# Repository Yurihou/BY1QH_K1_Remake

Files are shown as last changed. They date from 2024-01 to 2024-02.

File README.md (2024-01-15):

# BY1QH_K1_Remake
CQ DE BH9DWE! Elecraft is a famous amateur radio manufacturer but its rather expensive to afford. These days I tried to read and understood the original equipment Elecraft K1's principle and managed to modify it. So I push the PCB files to my GitHub and share it to all HAMs.

Firstly I read the manual and understood the schematic diagram of K1, found some components, such as JFET J309, is not available in online shopping network. So I modified the design a little bit. Then I bought and soldered the components of receiver of K1 on the board. After a series of debugging, I managed to make the circuit receiving CW signals on amateur bands. The testing video refers to https://www.bilibili.com/video/BV1d5411i7so
68414c2a40aba171e41130ed85432a5

The receiver is succeed in receiving but there is still some problems such as amplifier noise, RF filter attenuation and frequency drift, so I tried to draw the circuit into PCB. If the PCB version works well, I will continue adding functions and modifying design to improve its performance, such as adding frequency display, PLL, multi-band filter and band controller, transmitter, SSB module, antenna tuneing unit and so on.

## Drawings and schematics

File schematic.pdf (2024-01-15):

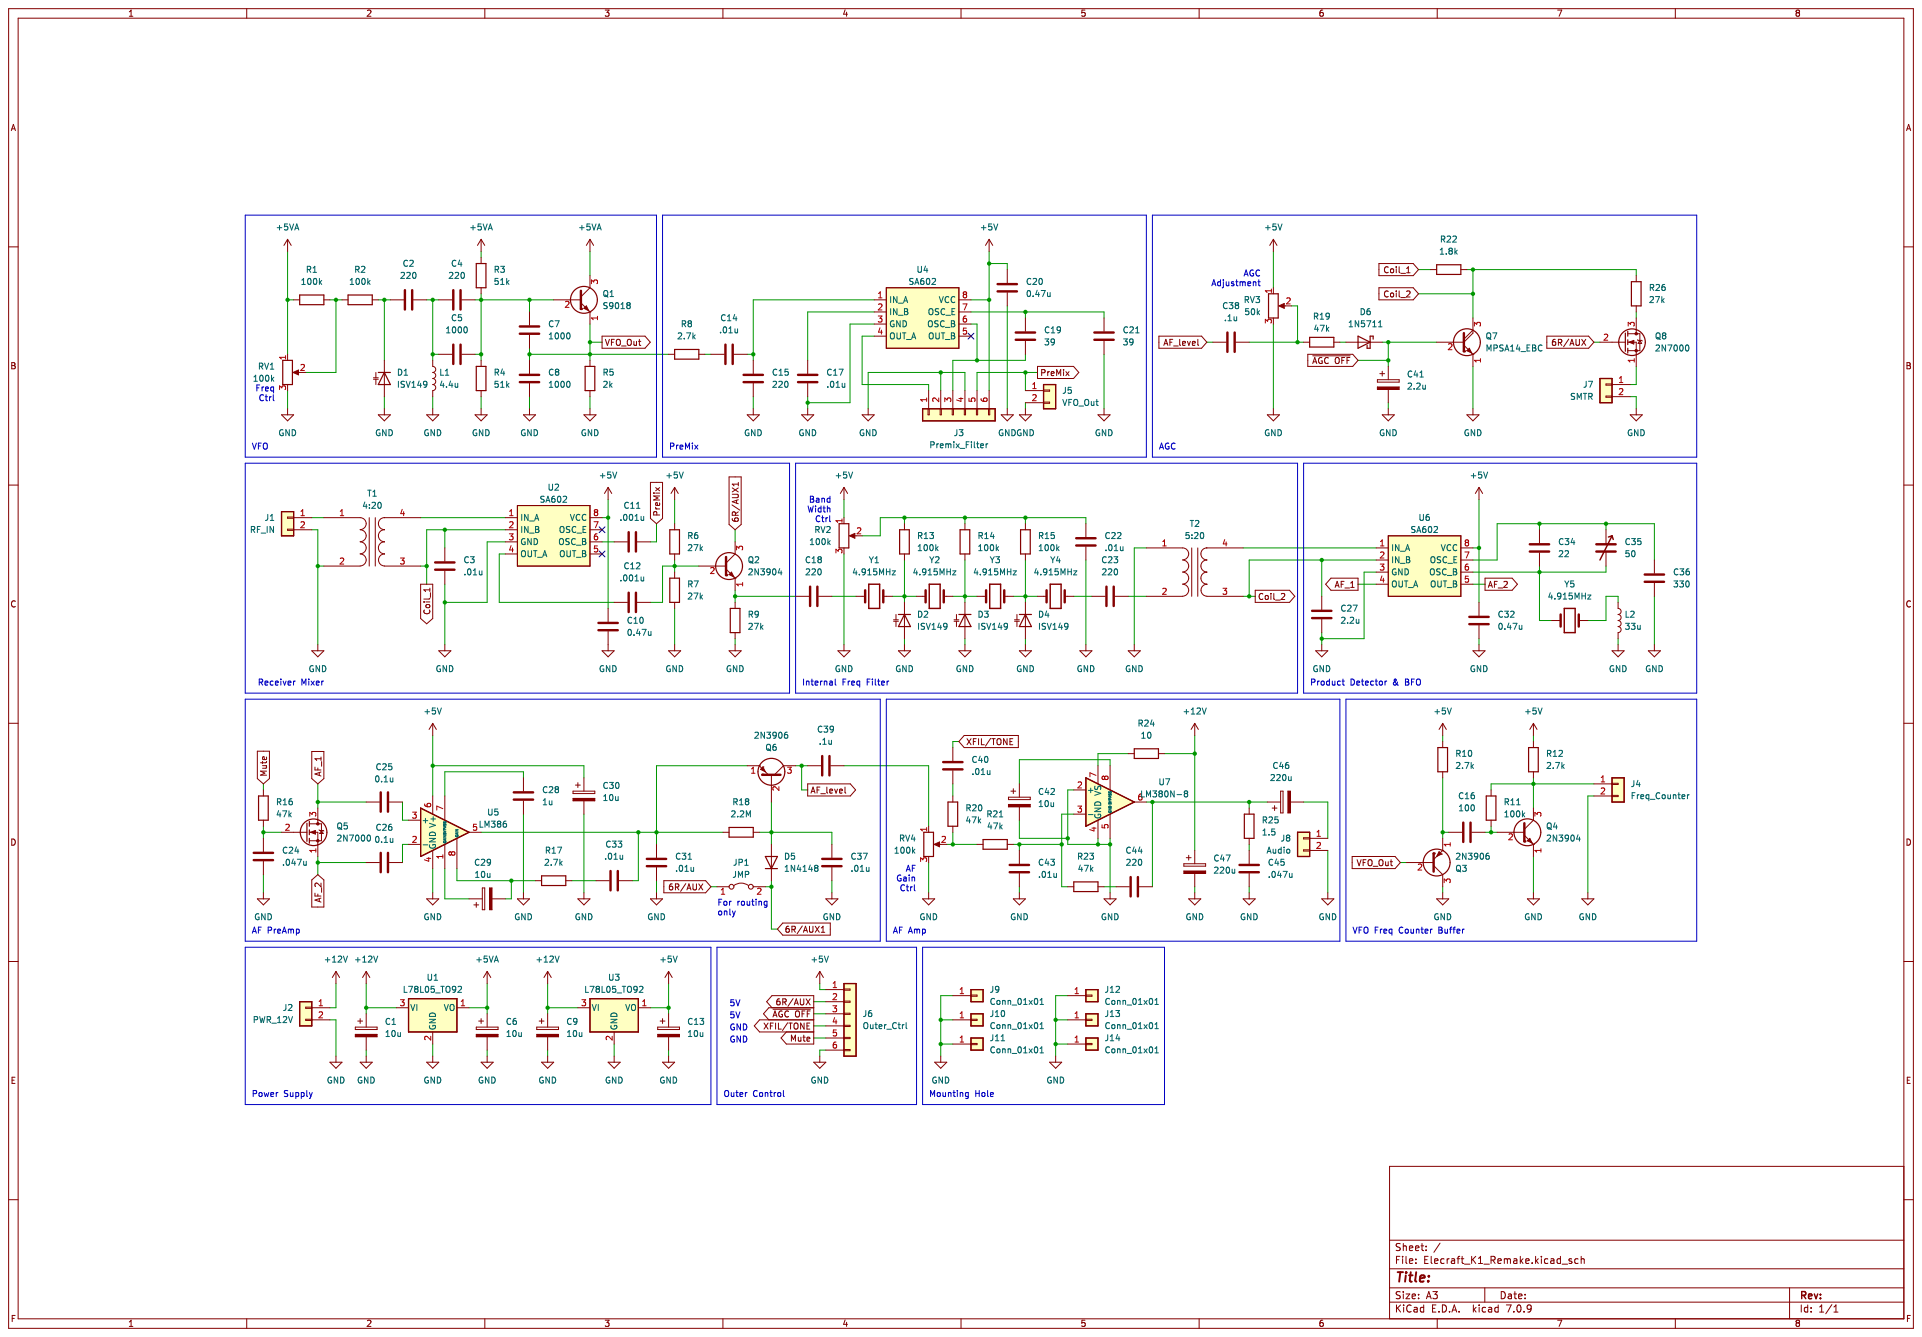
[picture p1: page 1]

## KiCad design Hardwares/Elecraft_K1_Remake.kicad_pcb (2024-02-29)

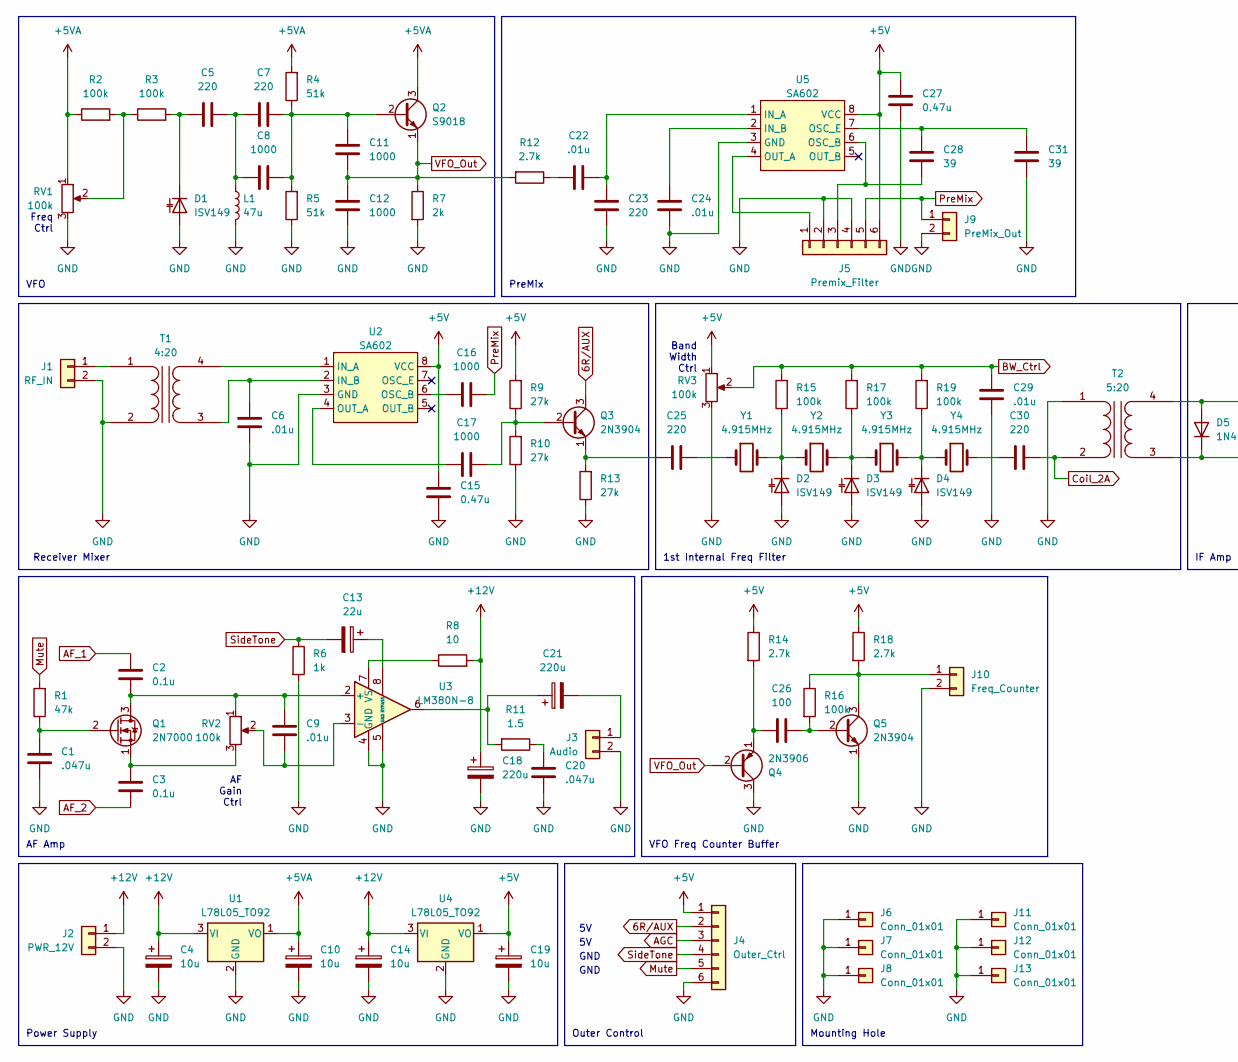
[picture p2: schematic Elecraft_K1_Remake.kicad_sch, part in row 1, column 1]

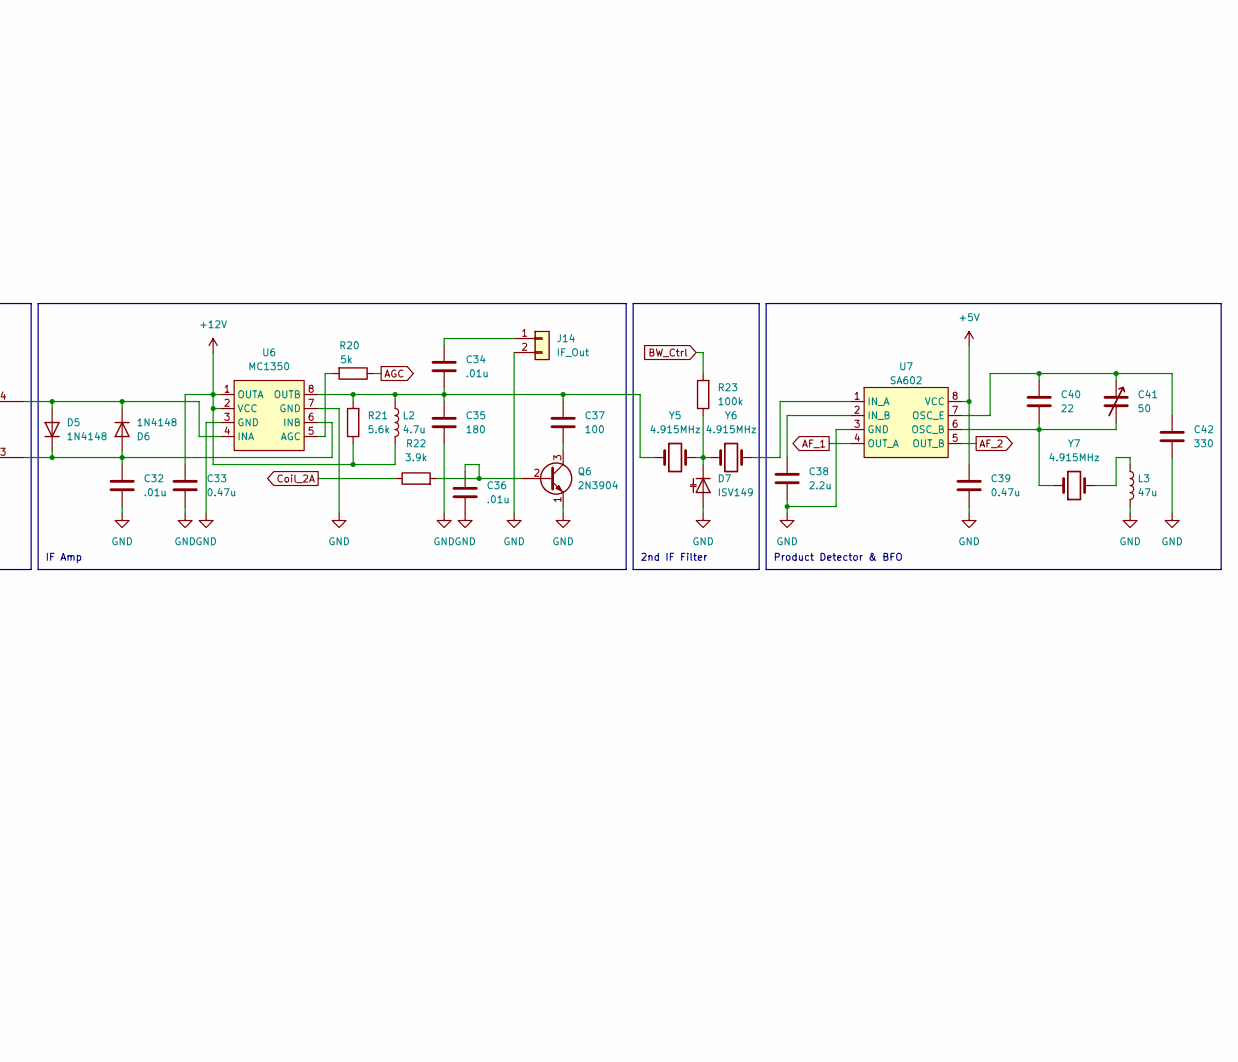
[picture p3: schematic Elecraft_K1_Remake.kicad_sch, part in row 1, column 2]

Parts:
C1, C20: .047u; C_Disc_D5.1mm_W3.2mm_P5.00mm
C2, C3: 0.1u; C_Disc_D5.1mm_W3.2mm_P5.00mm
C4, C10, C14, C19: 10u; CP_Radial_D5.0mm_P2.50mm
C5, C7, C23, C25, C30: 220; C_Disc_D5.1mm_W3.2mm_P5.00mm
C6, C9, C22, C24, C29, C32, C34, C36: .01u; C_Disc_D5.1mm_W3.2mm_P5.00mm
C8, C11, C12, C16, C17: 1000; C_Disc_D5.1mm_W3.2mm_P5.00mm
C13: 22u; CP_Radial_D8.0mm_P2.50mm
C15, C27, C33, C39: 0.47u; C_Disc_D5.1mm_W3.2mm_P5.00mm
C18, C21: 220u; CP_Radial_D8.0mm_P2.50mm
C26, C37: 100; C_Disc_D5.1mm_W3.2mm_P5.00mm
C28, C31: 39; C_Disc_D5.1mm_W3.2mm_P5.00mm
C35: 180; C_Disc_D5.1mm_W3.2mm_P5.00mm
C38: 2.2u; CP_Radial_D5.0mm_P2.50mm
C40: 22; C_Disc_D5.1mm_W3.2mm_P5.00mm
C41: 50; CP_Radial_Tantal_D6.0mm_P5.00mm
C42: 330; C_Disc_D5.1mm_W3.2mm_P5.00mm
D1, D2, D3, D4, D7: ISV149; TO-92-2
D5, D6: 1N4148; D_DO-35_SOD27_P7.62mm_Horizontal
J1: RF_IN; JST_XH_S2B-XH-A_1x02_P2.50mm_Horizontal
J2: PWR_12V; JST_XH_S2B-XH-A_1x02_P2.50mm_Horizontal
J3: Audio; JST_XH_S2B-XH-A_1x02_P2.50mm_Horizontal
J4: Outer_Ctrl; PinSocket_1x06_P2.54mm_Vertical
J5: Premix_Filter; PinSocket_1x06_P2.54mm_Vertical
J6, J7, J8, J11, J12, J13: Conn_01x01; MountingHole_3.2mm_M3_ISO14580_Pad
J9: PreMix_Out; JST_XH_S2B-XH-A_1x02_P2.50mm_Horizontal
J10: Freq_Counter; JST_XH_S2B-XH-A_1x02_P2.50mm_Horizontal
J14: IF_Out; JST_XH_S2B-XH-A_1x02_P2.50mm_Horizontal
L1, L3: 47u; L_Axial_L7.0mm_D3.3mm_P12.70mm_Horizontal_Fastron_MICC
L2: 4.7u; L_Axial_L7.0mm_D3.3mm_P12.70mm_Horizontal_Fastron_MICC
Q1: 2N7000; TO-92_Inline
Q2: S9018; TO-92_Inline
Q3, Q5, Q6: 2N3904; TO-92_Inline
Q4: 2N3906; TO-92_Inline
R1: 47k; R_Axial_DIN0207_L6.3mm_D2.5mm_P7.62mm_Horizontal
R2, R3, R15, R16, R17, R19, R23: 100k; R_Axial_DIN0207_L6.3mm_D2.5mm_P7.62mm_Horizontal
R4, R5: 51k; R_Axial_DIN0207_L6.3mm_D2.5mm_P7.62mm_Horizontal
R6: 1k; R_Axial_DIN0207_L6.3mm_D2.5mm_P7.62mm_Horizontal
R7: 2k; R_Axial_DIN0207_L6.3mm_D2.5mm_P7.62mm_Horizontal
R8: 10; R_Axial_DIN0207_L6.3mm_D2.5mm_P7.62mm_Horizontal
R9, R10, R13: 27k; R_Axial_DIN0207_L6.3mm_D2.5mm_P7.62mm_Horizontal
R11: 1.5; R_Axial_DIN0207_L6.3mm_D2.5mm_P7.62mm_Horizontal
R12, R14, R18: 2.7k; R_Axial_DIN0207_L6.3mm_D2.5mm_P7.62mm_Horizontal
R20: 5k; R_Axial_DIN0207_L6.3mm_D2.5mm_P7.62mm_Horizontal
R21: 5.6k; R_Axial_DIN0207_L6.3mm_D2.5mm_P7.62mm_Horizontal
R22: 3.9k; R_Axial_DIN0207_L6.3mm_D2.5mm_P7.62mm_Horizontal
RV1, RV2, RV3: 100k; JST_XH_S3B-XH-A_1x03_P2.50mm_Horizontal
T1: 4:20; Transformer_Toroid_Horizontal_D12.5mm_Amidon-T44
T2: 5:20; Transformer_Toroid_Horizontal_D12.5mm_Amidon-T44
U1, U4: L78L05_TO92; TO-92_Inline
U2, U5, U7: SA602; DIP-8_W7.62mm_Socket
U3: LM380N-8; DIP-8_W7.62mm_Socket
U6: MC1350; DIP-8_W7.62mm_Socket
Y1, Y2, Y3, Y4, Y5, Y6, Y7: 4.915MHz; Crystal_HC49-U_Vertical

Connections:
6R/AUX: J4.2, Q3.3 (C)
+5V: C15.2, C19.1, C27.2, C39.2, J4.1, J5.6, R9.2, R14.1, R18.1, RV3.1, U2.8 (VCC), U4.1 (VO), U5.8 (VCC), U7.8 (VCC)
+5VA: C10.1, Q2.3 (C), R2.1, R4.2, RV1.1, U1.1 (VO)
+12V: C4.1, C14.1, C18.1, C33.2, J2.1, L2.2, R8.2, R21.1, U1.3 (VI), U4.3 (VI), U6.1 (OUTA), U6.2 (VCC)
AF_1: C2.1, U7.4 (OUT_A)
AF_2: C3.1, U7.5 (OUT_B)
AGC: J4.3, R20.1
BW_Ctrl: C29.1, R15.2, R17.2, R19.2, R23.2, RV3.2
Coil_2A: C30.2, R22.1, T2.2 (AB)
GND: C1.2, C4.2, C6.2, C10.2, C12.2, C14.2, C15.1, C18.2, C19.2, C20.2, C23.1, C24.2, C27.1, C29.2, C31.2, C32.2, C33.1, C35.1, C36.2, C38.2, C39.1, C42.2, D1.2 (A), D2.2 (A), D3.2 (A), D4.2 (A), D7.2 (A), J1.2, J2.2, J3.2, J4.6, J5.2, J5.4, J6.1, J7.1, J8.1, J9.2, J10.2, J11.1, J12.1, J13.1, J14.2, L1.2, L3.2, Q4.3 (C), Q5.1 (E), Q6.1 (E), R5.1, R6.2, R7.2, R10.1, R13.1, RV1.3, RV3.3, T1.2 (AB), T2.1 (AA), U1.2 (GND), U2.3 (GND), U3.4 (GND), U3.5 (GND), U4.2 (GND), U5.3 (GND), U6.3 (GND), U6.7 (GND), U7.3 (GND)
Mute: J4.5, R1.2
unnamed: C5.1, C7.2, C8.2, L1.1
unnamed: C20.1, R11.1
unnamed: C21.1, R11.2, U3.6
unnamed: C22.2, R12.1
unnamed: C25.2, Y1.1
unnamed: C30.1, Y4.2
unnamed: C5.2, D1.1 (K), R3.2
unnamed: D2.1 (K), R15.1, Y1.2, Y2.1
unnamed: D3.1 (K), R17.1, Y2.2, Y3.1
unnamed: D4.1 (K), R19.1, Y3.2, Y4.1
unnamed: D5.2 (A), D6.1 (K), T2.4 (SB), U6.4 (INA)
unnamed: C32.1, D5.1 (K), D6.2 (A), T2.3 (SA), U6.6 (INB)
unnamed: D7.1 (K), R23.1, Y5.2, Y6.1
unnamed: J1.1, T1.1 (AA)
unnamed: C21.2, J3.1
unnamed: J5.1, U5.4 (OUT_A)
unnamed: C28.2, J5.3, U5.6 (OSC_B)
unnamed: J10.1, Q5.3 (C), R16.1, R18.2
unnamed: C34.1, J14.1
unnamed: L3.1, Y7.2
unnamed: C2.2, C9.1, Q1.3 (D), RV2.1, U3.2 (+)
unnamed: C1.1, Q1.2 (G), R1.1
unnamed: C3.2, Q1.1 (S), RV2.3
unnamed: C7.1, C8.1, C11.1, Q2.2 (B), R4.1, R5.2
unnamed: C17.2, Q3.2 (B), R9.1, R10.2
unnamed: C25.1, Q3.1 (E), R13.2
unnamed: C26.2, Q4.1 (E), R14.2
unnamed: C26.1, Q5.2 (B), R16.2
unnamed: C36.1, Q6.2 (B), R22.2
unnamed: C37.1, Q6.3 (C)
unnamed: R2.2, R3.1, RV1.2
unnamed: C6.1, T1.3 (SA), U2.2 (IN_B)
unnamed: T1.4 (SB), U2.1 (IN_A)
unnamed: C16.1, U2.6 (OSC_B)
unnamed: C17.1, U2.4 (OUT_A)
unnamed: C9.2, RV2.2, U3.3 (-)
unnamed: C13.1, U3.8 (BYPASS)
unnamed: R8.1, U3.7 (VS)
unnamed: C22.1, C23.2, U5.1 (IN_A)
unnamed: C24.1, U5.2 (IN_B)
unnamed: C28.1, C31.1, U5.7 (OSC_E)
unnamed: R20.2, U6.5 (AGC)
unnamed: C34.2, C35.2, C37.2, L2.1, R21.2, U6.8 (OUTB), Y5.1
unnamed: U7.1 (IN_A), Y6.2
unnamed: C38.1, U7.2 (IN_B)
unnamed: C40.2, C41.2, U7.6 (OSC_B), Y7.1
unnamed: C40.1, C41.1, C42.1, U7.7 (OSC_E)
PreMix: C16.2, J5.5, J9.1
SideTone: C13.2, J4.4, R6.1
VFO_Out: C11.2, C12.1, Q2.1 (E), Q4.2 (B), R7.1, R12.2

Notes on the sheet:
2nd IF Filter
Band Width Ctrl
VFO Freq Counter Buffer
Power Supply
GND
Freq Ctrl
PreMix
Mounting Hole
Outer Control
VFO
Product Detector & BFO
AF Gain Ctrl
AF Amp
Receiver Mixer
1st Internal Freq Filter
IF Amp

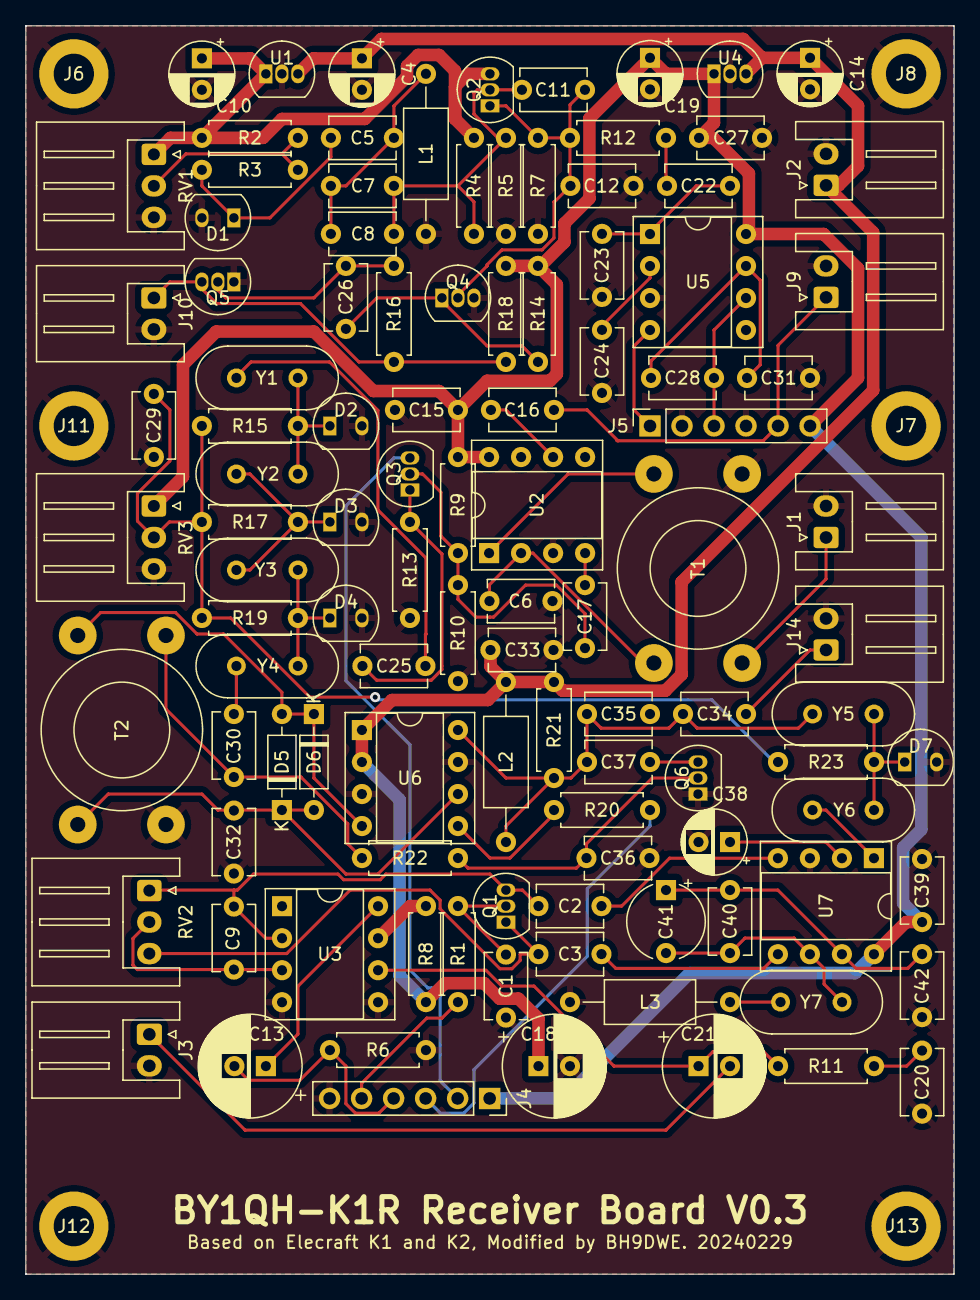
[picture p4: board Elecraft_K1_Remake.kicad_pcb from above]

Board: 2 copper layers, 73.7 x 99.1 mm, 114 parts (0 on the bottom side), 61 nets.

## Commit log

2024-01-15 Add hardware PCB files
    [Elecraft_K1_Remake-B_Cu.gbr, Elecraft_K1_Remake-B_Mask.gbr, Elecraft_K1_Remake-B_Paste.gbr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]
2024-01-15 Update and rename Elecraft_K1_Remake.kicad_pcb to Hardwares/Elecraft_K1_Remake.kicad_pcb
    [Elecraft_K1_Remake.kicad_pcb]
2024-01-15 Update and rename Elecraft_K1_Remake.kicad_sch to Hardwares/Elecraft_K1_Remake.kicad_sch
    [Elecraft_K1_Remake.kicad_sch]
